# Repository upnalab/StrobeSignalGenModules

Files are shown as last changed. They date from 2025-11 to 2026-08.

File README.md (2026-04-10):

# StrobeSignalGenModules
Tiny Modules to generate signals mainly to flash lights.
In general, they use a powerbank a usb-c trigger to get 5V or 12V, an Arduino to generate the signals, Encoder+OLED as UI, and a L298N to amplify.

* PowerBank -> USBTrig
* UsbTrig.V -> Arduino.VIn, L298N.V+
* UsbTrig.GND -> Arduino.GND, L298N.GND

* Arduino.GND -> OLED.GND, Encoder1.GND, Encoder2.GND
* Arduino.5V -> OLED.+, Encoder1.+, Encoder2.+

* Arduino.A4, A5 -> OLED.SDAT, SCLK
* Arduino.D3, D4, D5 -> Encoder1.CLK, DT, SWB
* Arduino.D2, D6, D7 -> Encoder2.CLK, DT, SWB [Optional]

* Arduino.D8,D9,D10,D11 -> L298N.IN1, IN2, IN3, IN4

Sometimes there is a step-up or step-down after the UsbTrig if a different voltage is needed

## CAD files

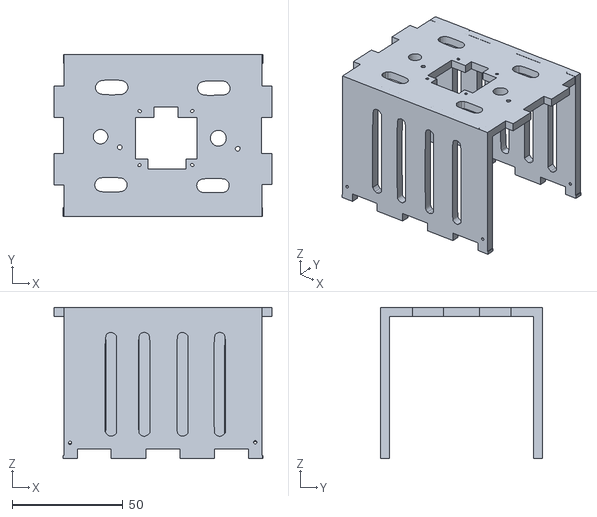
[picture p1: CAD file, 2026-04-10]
mech/caseTop.stl
98.3 x 73.2 x 68.2

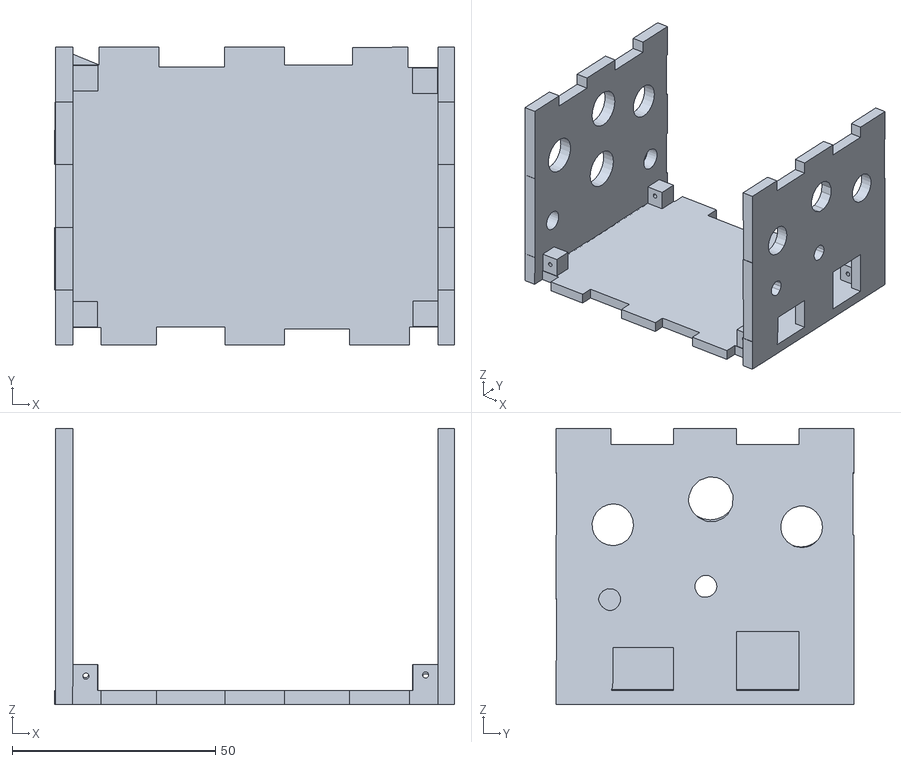
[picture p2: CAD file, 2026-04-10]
mech/caseBottom.stl
98.3 x 73.2 x 67.8

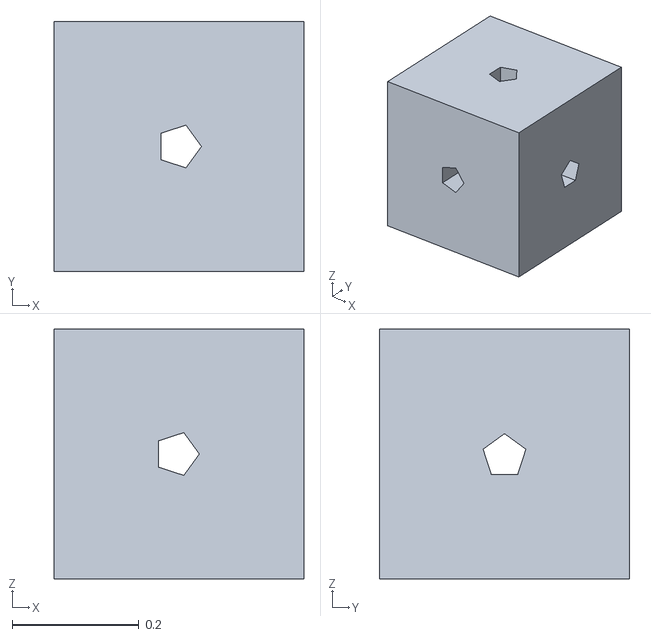
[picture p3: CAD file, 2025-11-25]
mech/cube1cm.stl
0.394 x 0.394 x 0.394

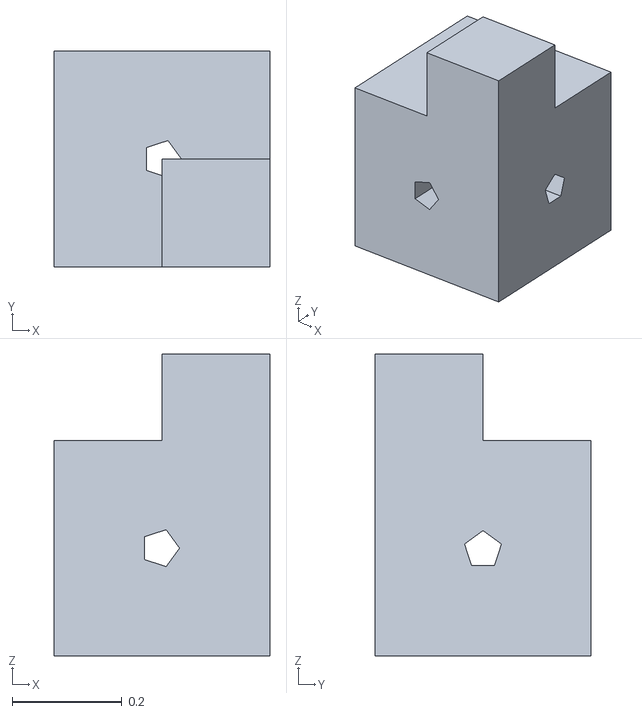
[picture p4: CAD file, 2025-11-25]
mech/cube1cmWithCon.stl
0.394 x 0.394 x 0.551

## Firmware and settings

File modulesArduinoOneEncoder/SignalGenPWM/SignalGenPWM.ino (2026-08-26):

#include <Arduino.h>
#include <avr/power.h>
#include <avr/pgmspace.h>
#include "PelicanController.h"

// -----------------------------------------------------------------------------
// PWM carrier selection: change ONLY this line.
// -----------------------------------------------------------------------------
#define PWM_CARRIER_31K25 0
#define PWM_CARRIER_40K   1
#define PWM_CARRIER_62K5  2

#define PWM_CARRIER PWM_CARRIER_62K5

// Arduino Uno/Nano, ATmega328P @ 16 MHz.
// D9 = OC1A, D10 = OC1B.
// Positive waveform: OCR1A=duty, OCR1B=0.
// Negative waveform: OCR1A=0, OCR1B=duty.

#define PWM_PIN_POS 9
#define PWM_PIN_NEG 10



#if PWM_CARRIER == PWM_CARRIER_31K25
constexpr uint32_t PWM_SAMPLE_RATE = 31250UL;
constexpr uint16_t PWM_TOP = 511;
#elif PWM_CARRIER == PWM_CARRIER_40K
constexpr uint32_t PWM_SAMPLE_RATE = 40000UL;
constexpr uint16_t PWM_TOP = 399;
#elif PWM_CARRIER == PWM_CARRIER_62K5
constexpr uint32_t PWM_SAMPLE_RATE = 62500UL;
constexpr uint16_t PWM_TOP = 255;
#else
#error Invalid PWM_CARRIER selection
#endif

PelicanController controller(3, 4, 5);

const char *WAVE_NAMES[] = {
  "Sine",
  "Square",
  "HalfSq",
  "Triang",
  "SawRis",
  "SawFal",
  NULL
};

enum WaveType {
  WAVE_SINE = 0,
  WAVE_SQUARE,
  WAVE_HALF_SQUARE,
  WAVE_TRIANGLE,
  WAVE_SAW_RISE,
  WAVE_SAW_FALL
};

// Only sine uses a LUT. Range: -127..+127.
const int8_t SINE_TABLE[256] PROGMEM = {
     0,    3,    6,    9,   12,   16,   19,   22,   25,   28,   31,   34,   37,   40,   43,   46,
    49,   51,   54,   57,   60,   63,   65,   68,   71,   73,   76,   78,   81,   83,   85,   88,
    90,   92,   94,   96,   98,  100,  102,  104,  106,  107,  109,  111,  112,  113,  115,  116,
   117,  118,  120,  121,  122,  122,  123,  124,  125,  125,  126,  126,  126,  127,  127,  127,
   127,  127,  127,  127,  126,  126,  126,  125,  125,  124,  123,  122,  122,  121,  120,  118,
   117,  116,  115,  113,  112,  111,  109,  107,  106,  104,  102,  100,   98,   96,   94,   92,
    90,   88,   85,   83,   81,   78,   76,   73,   71,   68,   65,   63,   60,   57,   54,   51,
    49,   46,   43,   40,   37,   34,   31,   28,   25,   22,   19,   16,   12,    9,    6,    3,
     0,   -3,   -6,   -9,  -12,  -16,  -19,  -22,  -25,  -28,  -31,  -34,  -37,  -40,  -43,  -46,
   -49,  -51,  -54,  -57,  -60,  -63,  -65,  -68,  -71,  -73,  -76,  -78,  -81,  -83,  -85,  -88,
   -90,  -92,  -94,  -96,  -98, -100, -102, -104, -106, -107, -109, -111, -112, -113, -115, -116,
  -117, -118, -120, -121, -122, -122, -123, -124, -125, -125, -126, -126, -126, -127, -127, -127,
  -127, -127, -127, -127, -126, -126, -126, -125, -125, -124, -123, -122, -122, -121, -120, -118,
  -117, -116, -115, -113, -112, -111, -109, -107, -106, -104, -102, -100,  -98,  -96,  -94,  -92,
   -90,  -88,  -85,  -83,  -81,  -78,  -76,  -73,  -71,  -68,  -65,  -63,  -60,  -57,  -54,  -51,
   -49,  -46,  -43,  -40,  -37,  -34,  -31,  -28,  -25,  -22,  -19,  -16,  -12,   -9,   -6,   -3
};

volatile uint32_t phaseIncrement = 0;
volatile uint8_t currentWave = WAVE_SINE;
volatile uint16_t amplitudeScale = 0;
volatile bool signalEnabled = true;

volatile uint32_t phaseAccumulator = 0;

// Returns a normalized signed sample, approximately -127..+127.
// Only sine touches flash; the other waveforms are integer expressions.
inline int8_t getWaveSample(uint8_t phase, uint8_t wave) {
  switch (wave) {
    case WAVE_SINE:
      return (int8_t)pgm_read_byte(&SINE_TABLE[phase]);

    case WAVE_SQUARE:
      return phase < 128 ? 127 : -127;

    case WAVE_HALF_SQUARE:
      // Positive pulse for half a period, zero for the other half.
      return phase < 128 ? 127 : 0;

    case WAVE_TRIANGLE: {
      // Starts at zero, rises positive, crosses zero, then goes negative.
      uint8_t quadrant = phase >> 6;
      uint8_t x = phase & 0x3F;
      if (quadrant == 0) return (int8_t)(x << 1);
      if (quadrant == 1) return (int8_t)(127 - (x << 1));
      if (quadrant == 2) return (int8_t)-(x << 1);
      return (int8_t)(-127 + (x << 1));
    }

    case WAVE_SAW_RISE: {
      int16_t v = (int16_t)phase - 128;
      if (v < -127) v = -127;
      return (int8_t)v;
    }

    case WAVE_SAW_FALL: {
      int16_t v = 127 - (int16_t)phase;
      if (v < -127) v = -127;
      return (int8_t)v;
    }
  }

  return 0;
}

void setupPWM();
void updateSignalParameters();
inline int8_t getWaveSample(uint8_t phase, uint8_t wave);

void setup() {
  power_adc_disable();
  ADCSRA = 0;
  power_spi_disable();
  TIMSK0 &= ~_BV(TOIE0);

  Serial.begin(115200);

  controller.addNumber("Freq", 0, 9999, 1500, 2);
  controller.addNumber("Amp", 0, 99, 50);
  controller.addStringList("Wave", WAVE_NAMES, WAVE_SINE);

  controller.init();
  setupPWM();
  updateSignalParameters();
}

void loop() {
  if (controller.update()) updateSignalParameters();
  if (controller.needsToRender()) controller.render();
}

void setupPWM() {
  pinMode(PWM_PIN_POS, OUTPUT);
  pinMode(PWM_PIN_NEG, OUTPUT);
  digitalWrite(PWM_PIN_POS, LOW);
  digitalWrite(PWM_PIN_NEG, LOW);

  noInterrupts();

  TCCR1A = 0;
  TCCR1B = 0;
  TCNT1 = 0;
  OCR1A = 0;
  OCR1B = 0;

  // Both OC1A (D9) and OC1B (D10) stay enabled in non-inverting PWM mode.
  // Prescaler is always 1. Only TOP / Fast-PWM mode changes.
#if PWM_CARRIER == PWM_CARRIER_31K25
  // 9-bit Fast PWM, TOP=511, Mode 6.
  // 16 MHz / 512 = 31.25 kHz.
  TCCR1A = _BV(COM1A1) | _BV(COM1B1) | _BV(WGM11);
  TCCR1B = _BV(WGM12) | _BV(CS10);

#elif PWM_CARRIER == PWM_CARRIER_40K
  // Fast PWM with ICR1 as TOP, TOP=399, Mode 14.
  // 16 MHz / (399 + 1) = 40 kHz.
  ICR1 = PWM_TOP;
  TCCR1A = _BV(COM1A1) | _BV(COM1B1) | _BV(WGM11);
  TCCR1B = _BV(WGM13) | _BV(WGM12) | _BV(CS10);

#elif PWM_CARRIER == PWM_CARRIER_62K5
  // 8-bit Fast PWM, TOP=255, Mode 5.
  // 16 MHz / 256 = 62.5 kHz.
  TCCR1A = _BV(COM1A1) | _BV(COM1B1) | _BV(WGM10);
  TCCR1B = _BV(WGM12) | _BV(CS10);
#endif

  TIFR1 = _BV(TOV1);
  TIMSK1 = _BV(TOIE1);

  interrupts();
}

void updateSignalParameters() {
  uint32_t freq100 = controller.getNumber(0);
  uint8_t amp = controller.getNumber(1);
  uint8_t wave = controller.getStringIndex(2);

  uint32_t newIncrement = 0;
  if (freq100 != 0) {
    newIncrement = ((uint64_t)freq100 << 32) / ((uint64_t)PWM_SAMPLE_RATE * 100ULL);
  }

  // Precompute amplitude scaling outside the ISR.
  // ISR keeps the cheap: duty = magnitude * amplitudeScale >> 7.
  // At Amp=99, magnitude=127 reaches PWM_TOP.
  const uint32_t denom = 99UL * 127UL;
  uint16_t newAmplitudeScale = ((uint32_t)amp * PWM_TOP * 128UL + denom - 1) / denom;

  noInterrupts();
  phaseIncrement = newIncrement;
  currentWave = wave;
  amplitudeScale = newAmplitudeScale;
  signalEnabled = (freq100 != 0 && amp != 0);
  interrupts();
}

ISR(TIMER1_OVF_vect) {
  phaseAccumulator += phaseIncrement;

  uint8_t phase = (uint8_t)(phaseAccumulator >> 24);
  int8_t sample = signalEnabled ? getWaveSample(phase, currentWave) : 0;

  uint8_t magnitude = sample < 0 ? (uint8_t)-sample : (uint8_t)sample;
  uint16_t duty = ((uint16_t)magnitude * amplitudeScale) >> 7;

  if (sample > 0) {
    OCR1A = duty;
    OCR1B = 0;
  } else if (sample < 0) {
    OCR1A = 0;
    OCR1B = duty;
  } else {
    OCR1A = 0;
    OCR1B = 0;
  }
}

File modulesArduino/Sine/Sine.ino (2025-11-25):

#include <Wire.h>
#include <EEPROM.h>
#include <avr/sleep.h>
#include <avr/power.h>
//external libs
#include <Encoder.h>
#include <Adafruit_GFX.h>
#include <Adafruit_SSD1306.h>
//internal
#include "EncoderControl.h"

Adafruit_SSD1306 display(128, 64, &Wire, -1); //A4->SDA and A5->SCL

#define N_SAMPLES 128 //with 256 it fails
#define HALF_SAMPLES (N_SAMPLES/2)
#define PWM_FR 20000

uint8_t LUT_SIGNALS[N_SAMPLES]; //each sample is: 2 bits port masks | 6 bits microswait (0 to 63 at most)

//#define N_SIGNALS 5
//square, sin, triang, sawRise, sawFall
#define MAX_VAL 80 //this is in uS, it is the period of the PWM freq minus some time for calculations
#define HALF_VAL (MAX_VAL/2)

// ---------- Encoders: better if first pin has interrups (D2,D3 in Nano
Encoder encFreq(3,4); //3 4 5
#define BTN_FREQ 5
Encoder encAmp(2,6); //2 6 7
#define BTN_AMP 7

EncoderControl freqCtrl(encFreq, BTN_FREQ, 1, 9999, 1500);   // start at 15 Hz it is divided by 100
EncoderControl ampCtrl(encAmp, BTN_AMP, 0, 100, 35);    // start at 35% 
bool switchedOn = false;

// ---------- EEPROM values: save/load with persistance
typedef struct{
  int32_t _signature;
  int16_t value1;
  int16_t value2;
  bool switchedOn;
} ConfigData;
ConfigData config;
void saveConfig() {
  config._signature = 0xBEEF;
  config.value1 = freqCtrl.getValue();
  config.value2 = ampCtrl.getValue();
  config.switchedOn = switchedOn;
  EEPROM.put(0, config);
}
void loadConfig() {
  EEPROM.get(0, config);
  if (config._signature != 0xBEEF){ //first time loading, put default values
      config._signature = 0xBEEF;
      config.value1 = 1500;
      config.value2 = 35;
      config.switchedOn = false;
      saveConfig();
  }
  freqCtrl.setValue( config.value1 );
  ampCtrl.setValue( config.value2 );
  switchedOn = config.switchedOn;
}


// ---------- Function prototypes ----------
void drawDisplay();
void uintToString(uint16_t val, char* str);
void gndPin(uint8_t pin) {pinMode(pin, OUTPUT); digitalWrite(pin, LOW);};
void fillInLUT();
void stopSignalGen();
void signalGen(int signalType, float fr);

void setup() {
  // turn off everything we can 
  power_adc_disable();
  ADCSRA = 0;
  power_spi_disable();
  //power_timer0_disable(); //disabling timer0 breaks the encoder library
  TIMSK0 &= ~_BV(TOIE0); //so we just disable its interrupt to avoid jitter

  pinMode(BTN_FREQ, INPUT_PULLUP);
  pinMode(BTN_AMP, INPUT_PULLUP);
  
  loadConfig();
  freqCtrl.setDigit( 2 );
  ampCtrl.setDigit( 0 );
  
  display.begin(SSD1306_SWITCHCAPVCC, 0x3C);
  display.setTextColor(SSD1306_WHITE);
  drawDisplay();

  Serial.begin(115200);
  
  fillInLUT();
  DDRB = 0b00000011; //set pins D8 to D9 as outputs
  PORTB = 0b00000000; //output low in all of them
  // initialize timer1 to interrupt at PWM_FR (usually 20kHz)
  noInterrupts();           // disable all interrupts
  TCCR1A = TCCR1B = TCNT1 = 0;
  OCR1A = (F_CPU / PWM_FR); 
  TCCR1B |= (1 << WGM12);   // CTC mode
  TCCR1B |= (1 << CS10);    // 1 prescaler, no prescaling
  interrupts();             // enable all interrupts
}

volatile uint8_t amplitude = 255;
bool needsUpdate = true;

void loop() {
  
  uint16_t ticksPressed = 0;

  freqCtrl.handleRotation(needsUpdate);
  freqCtrl.handleButton(needsUpdate, ticksPressed);
  if (ticksPressed > 30){ //30 is around 1s -> save current parameters to EPROM
    saveConfig();
  }

  ampCtrl.handleRotation(needsUpdate);
  ampCtrl.handleButton(needsUpdate, ticksPressed);
  if (ticksPressed > 30){ //switch on/off
    Serial.println( switchedOn );
    if( switchedOn ){ //it is on, we switch off
      stopSignalGen();
    }
    switchedOn = switchedOn?false:true;
    needsUpdate = true;
  }

  if (needsUpdate) {
    drawDisplay();
    if (switchedOn){
      amplitude = ampCtrl.getValue() * 255 / 100;
      signalGen(1, freqCtrl.getValue() / 100.0f );
    }
  }

  delay(20);
}

volatile uint32_t indexShift24 = 0;
volatile uint32_t indexIncShift24 = 4294967;

ISR(TIMER1_COMPA_vect) { // timer compare interrupt service routine
  static uint8_t portMask = 0b00000001;
  static uint8_t microsHigh = HALF_VAL;
  PORTB = portMask; //switch on the corresponding pins 
  delayMicroseconds(microsHigh);
  
  PORTB = 0b00000000; //all off

  indexShift24 += indexIncShift24; //increase. overflow makes it cycle
  
  const uint8_t sample = LUT_SIGNALS[ (indexShift24 >> 24) % N_SAMPLES];   //get sample  
  portMask = (sample >> 6) ;   //extract pin mask
  microsHigh = (sample & 0b00111111) * amplitude / 256; //extract wait micros
}

void stopSignalGen(){
  noInterrupts();  
  TIMSK1 &= ~(1 << OCIE1A); //disable the timer interrupt
  PORTB = 0b00000000;
  interrupts();
}

void signalGen(int signalType, float fr){
  //currentSignal = signalType % N_SIGNALS;
  TIMSK1 |= (1 << OCIE1A); //enable timer interrupt
  indexIncShift24 = (uint32_t) ( (float)((uint32_t)1<<24) * (float)N_SAMPLES * fr / (float)PWM_FR);
}

void drawDisplay() {
  char str[] = "0000";
  display.clearDisplay();
  //display.setRotation(2);
  
  display.setCursor(0, 0);
  display.setTextSize(1);
  display.print("Freq (Hz)");
  display.setCursor(0, 10);
  display.setTextSize(2);
  uintToString(freqCtrl.getValue(), str);
  display.print(str);
  display.drawPixel(23, 25, SSD1306_WHITE);
  display.fillRect(1+(3- freqCtrl.getDigit() )*12, 29, 10, 2, SSD1306_WHITE);    // Highlight frequency digit
  
  display.setCursor(0, 35);
  display.setTextSize(1);
  display.print("Amp (%)");
  display.setCursor(0, 45);
  display.setTextSize(2);
  uintToString(ampCtrl.getValue(), str);
  display.print(str);
  //display.drawPixel(35, 59, SSD1306_WHITE);
  display.fillRect(1+(3- ampCtrl.getDigit() )*12, 63, 10, 2, SSD1306_WHITE); //duty digit

  display.setCursor(100, 1);
  display.setTextSize(1);
  if (switchedOn){
    display.print("ON");
  }else{
    display.print("off");
  }
  
  display.display();
}

void uintToString(uint16_t val, char* str) {
  int len = 0;
  for (; str[len] != '\0'; len++)
    str[len] = '0';

  for (int i = len - 1; val > 0 && i >= 0; i--) {
    str[i] = (val % 10) + '0';
    val /= 10;
  }
}


inline uint8_t packSample(uint8_t val) {
  if (val >= HALF_VAL){
    return 0b01000000 | (val-HALF_VAL);  
  }else{
    return 0b10000000 | (HALF_VAL-val);
  }
}

void fillInLUT() {
  for (int i = 0; i < N_SAMPLES; ++i) {/*
    LUT_SIGNALS[0][i] = packSample( i < HALF_SAMPLES ? MAX_VAL : 0 ); //square wave
    const double v = cos( i * 2.0 * PI / N_SAMPLES ); //sinusoidal
    LUT_SIGNALS[1][i] = packSample( (byte) ((v + 1.0) / 2.0 * MAX_VAL) ); //map from -1,1  to  0,MAX
    LUT_SIGNALS[2][i] = packSample( abs( i*MAX_VAL/N_SAMPLES*2 - MAX_VAL ) ); //triangular
    LUT_SIGNALS[3][i] = packSample( i * MAX_VAL / N_SAMPLES ); //saw-tooth rise
    LUT_SIGNALS[4][i] = packSample( (N_SAMPLES-i) * MAX_VAL / N_SAMPLES ); //saw-tooth fall
    */
    const double v = cos( i * 2.0 * PI / N_SAMPLES ); //sinusoidal
    LUT_SIGNALS[i] = packSample( (byte) ((v + 1.0) / 2.0 * MAX_VAL) ); //map from -1,1  to  0,MAX
  }
}

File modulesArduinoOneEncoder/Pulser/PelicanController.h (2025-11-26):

#include <Arduino.h>
#include <Wire.h>
//external libs
#include <Encoder.h>
#include <Adafruit_GFX.h>
#include <Adafruit_SSD1306.h>
#include <EEPROM.h>

#define PELICAN_CTRL_MAX_PARAMS 4
#define PELICAN_EEPROM_CODE 0x5ECB

class PelicanController {
public:
  bool printDebugInfo = false;

  PelicanController(int encPinClk, int encPinData, int btn, uint16_t ticksButtonPress=400)
    : display(128, 64, &Wire, -1),
      encoder(encPinClk, encPinData),
      pinBtn(btn),
      ticksForButtonPress(ticksButtonPress){

  }

  void init() {
    pinMode(pinBtn, INPUT_PULLUP);
    lastBtn = digitalRead(pinBtn);
    encLastPos = encoder.read() / 4;
    loadFromEEPROM();
    display.begin(SSD1306_SWITCHCAPVCC, 0x3C);
    display.setTextColor(SSD1306_WHITE);
    render();
  }

  void addNumber(const char* name, long minV, long maxV, long val, uint8_t nDecimals=0) {
    if (paramCount >= PELICAN_CTRL_MAX_PARAMS) return;
    Param& p = params[paramCount++];
    p.name = name;
    p.type = NUM;
    p.num.minVal = minV;
    p.num.maxVal = maxV;
    p.num.value = val;
    p.num.nDigits = calcNDigits(maxV);
    p.num.nDecimals = nDecimals;
  }

  void addBoolean(const char* name, bool val) {
    if (paramCount >= PELICAN_CTRL_MAX_PARAMS) return;
    Param& p = params[paramCount++];
    p.name = name;
    p.type = BOOL;
    p.boolean.value = val;
  }

  void addStringList(const char* name, const char** opts) {
    if (paramCount >= PELICAN_CTRL_MAX_PARAMS) return;
    Param& p = params[paramCount++];
    p.name = name;
    p.type = STR;
    p.str.options = opts;
    p.str.index = 0;
    p.str.nOptions = countOptions(opts);
  }

  // -------------------------------------------------------------------
  // MAIN UPDATE (returns true if a parameter changed)
  // -------------------------------------------------------------------
  bool update() {
    needsUpdate = false;

    ticks++;

    // ------------------ ROTARY ENCODER --------------------
    long newPos = encoder.read() / 4;
    long delta = newPos - encLastPos;
    if (delta != 0) {
      rotate(delta);
      encLastPos = newPos;
      needsRender = true;
    }

    // ----------------------- BUTTON ------------------------
    bool btn = !digitalRead(pinBtn);  // active low
    uint32_t diff = ticks - btnDownTick;
    // button pressed (with debounce)
    if (btn && !lastBtn && diff > ticksForButtonPress) {
      if (printDebugInfo){
        Serial.print( "pressing" );
        Serial.println( diff );
      }
      click();  
      btnDownTick = ticks;
      needsRender = true;
    }

    // button released
    else if (!btn && lastBtn) {
      if (printDebugInfo){
        Serial.print( "releasing" );
        Serial.println( diff );
      }
      if (diff > ticksForButtonPress * 1024) {   // long press → save
        if (printDebugInfo) Serial.println( "Saving config" );
        saveToEEPROM(); 
      }
      /* else if (diff > ticksForButtonPress * 1024) { // medium press → cycle mode
        if (printDebugInfo) Serial.println( "Changing mode" );
        mode = (mode + 1) % MODE_LAST_MODE;
        needsRender = true;
      }
      */
      btnDownTick = ticks;
    }

    lastBtn = btn;

    return needsUpdate;
  }

  // -------------------------------------------------------------------
  // RENDER SCREEN
  // -------------------------------------------------------------------
  void render() {
    display.clearDisplay();

    for (int i = 0; i < paramCount; i++) {
      Param& p = params[i];
      int y = i * 16;
      display.setCursor(0, y);
      display.setTextSize(1);
      display.print(p.name);

      display.setCursor(48, y);
      display.setTextSize(2);
      printValue(p);

      if (p.type == NUM && p.num.nDecimals > 0){
        int xPos = 47 + (p.num.nDigits - p.num.nDecimals) * 12;
        display.drawPixel(xPos, y+14, SSD1306_WHITE);
      }
    }

    int yPos = current * 16;
    display.fillRect(45, yPos, (state == DIALING_DIGIT ? 2 : 1), 16, SSD1306_WHITE);
    if (state == SELECTING_DIGIT || state == DIALING_DIGIT ||
        mode == MODE_DIGIT_ROT || mode == MODE_DIGIT_PRESS) {
      Param& p = params[current];
      if (p.type == NUM) {
        int xPos = 48 + (p.num.nDigits - currentDigit - 1) * 12;
        if (state == DIALING_DIGIT) {
          display.drawRect(xPos, yPos, 12, 16, SSD1306_WHITE);
        } else {
          display.drawRect(xPos, yPos + 15, 12, 1, SSD1306_WHITE);
        }
      }
    }


    display.display();
    needsRender = false;
  }

  // -------------------------------------------------------------------
  // GETTERS
  // -------------------------------------------------------------------
  boolean needsToRender() const {
    return needsRender;
  }

  long getNumber(uint8_t i) const {
    return params[i].num.value;
  }
  bool getBoolean(uint8_t i) const {
    return params[i].boolean.value;
  }
  const uint8_t getStringIndex(uint8_t i) const {
    return params[i].str.index;
  }
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

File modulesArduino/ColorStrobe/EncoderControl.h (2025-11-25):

class EncoderControl {
public:
  EncoderControl(Encoder& encoder, uint8_t buttonPin, int16_t minVal, int16_t maxVal, int16_t initialValue)
    : enc(encoder), btnPin(buttonPin), minVal(minVal), maxVal(maxVal), lastPos(0), lastBtnState(HIGH),
      value(constrain(initialValue, minVal, maxVal)), digit(0) {}

  int16_t getValue() const { return value; }
  void setValue(int16_t val) {value = constrain(val, minVal, maxVal); }
  uint8_t getDigit() const { return digit; }
  void setDigit(uint8_t d) {digit = constrain(d, 0, 3); }
  
  bool handleRotation(bool& needsUpdate) {
    long newPos = enc.read() / 4; // Adjust sensitivity
    if (newPos != lastPos) {
      long delta = newPos - lastPos;
      int16_t step = 1;
      if (digit == 1) step = 10;
      else if (digit == 2) step = 100;
      else if (digit == 3) step = 1000;
      value -= delta * step;
      value = constrain(value, minVal, maxVal);
      lastPos = newPos;
      needsUpdate = true;
    }
  }

  void handleButton(bool& needsUpdate, uint16_t& tPressed) {
    tPressed = 0;
    uint8_t btnState = digitalRead(btnPin);
    if (btnState == LOW){ //pressed
      if (lastBtnState == HIGH){
        digit = (digit + 1) % 4;
        needsUpdate = true;
      }
      ticksPressed += 1;
    }else{ //not pressed
      tPressed = ticksPressed;
      ticksPressed = 0;
    }
    lastBtnState = btnState;
  }
  
private:
  Encoder& enc;
  long lastPos;

  const uint8_t btnPin;
  uint8_t lastBtnState;
  uint8_t digit;
  uint16_t ticksPressed;

  int16_t value;
  const int16_t minVal, maxVal;
};

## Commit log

2025-11-26 added 3dprinted case
    [caseBottom.stl, caseTop.stl]
2025-11-27 Update README with rough module description and wiring
2025-11-27 Format wiring instructions in README.md
2026-04-10 removed off mode from Sine
    [caseBottom.stl, caseTop.stl]
2026-08-26 added signalgen for a half-bridge PWM (class-d without the filter)
